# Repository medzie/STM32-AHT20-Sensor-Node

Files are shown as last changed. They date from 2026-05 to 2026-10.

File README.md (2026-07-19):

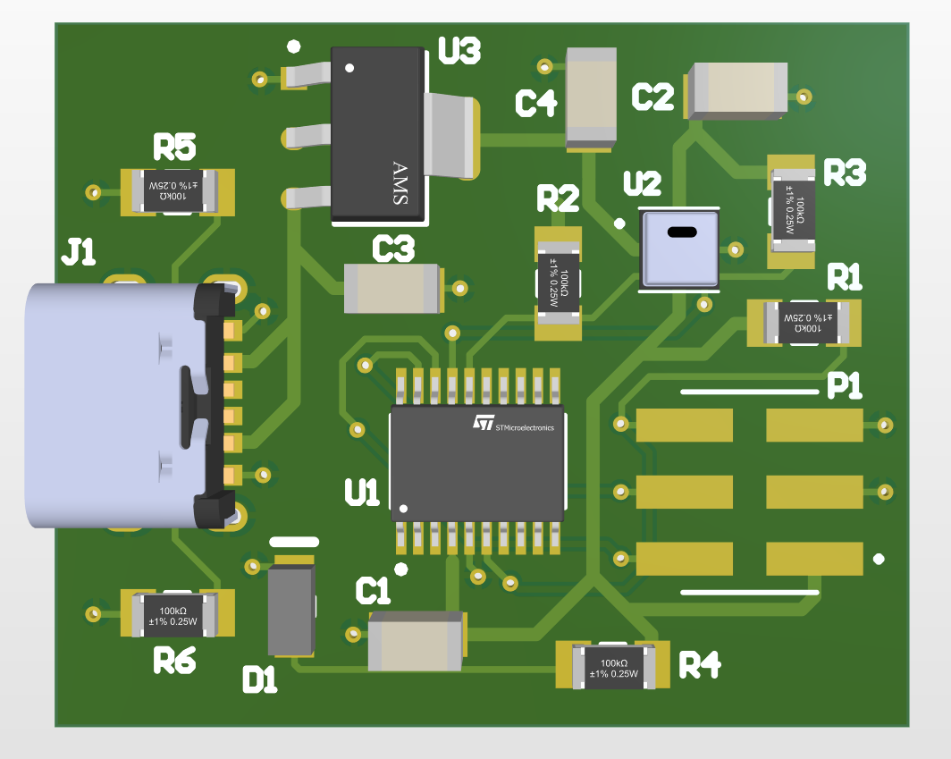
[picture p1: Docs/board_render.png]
STM32 AHT20 Sensor Node Board Render


# STM32 Environmental Sensor (AHT20)

## Overview
This project is a custom environmental sensor node designed to measure temperature and humidity. It is built around the STM32G030F6P6 microcontroller and the AHT20 sensor. The goal of the project was to design a complete hardware-software system, from the schematic and PCB layout to bare-metal firmware implementation.

## Key Features
* **Microcontroller:** STM32G030F6P6 (Cortex-M0+).
* **Sensor:** AHT20 (I2C interface) for high-accuracy climate monitoring.
* **Power Supply:** USB-C 6-pin interface with 5V to 3.3V regulation.
* **Programming:** Standard 2x3 SWD header for ST-Link.
* **Firmware:** Developed in C using direct register access (Bare-Metal).

## Hardware Design
The hardware was designed in Altium Designer. 

**[View Full Schematic (PDF)](Docs/schema.pdf)**

Key design choices include:
* **Voltage Regulation:** AMS1117-3.3 (SOT-223) to provide stable power for the MCU and sensor.
* **USB-C Integration:** 5.1kΩ pull-down resistors on CC1/CC2 lines to ensure compatibility with modern USB-C chargers.
* **Component Selection:** Primarily SMD 1206 footprints for easy manual assembly while maintaining a compact form factor.
* **PCB:** 2-layer design with a solid ground plane for improved EMI performance.

## Project Structure
* `/hardware` - Altium Designer schematics and PCB layout files.
* `/software` - Source code (C), including I2C drivers and peripheral initialization.
* `/Docs` - Datasheets, technical documentation, and project media.

## Learning Objectives
* Mastering professional PCB design workflow in Altium Designer.
* Understanding I2C communication protocol at the register level.
* Implementing hardware-specific features like USB-C power negotiation.

Project developed as part of technical self-education in Embedded Systems.

---

## Project Presentation

### Live Sensor Readings (STM32CubeIDE)
AHT20 Readings

### Assembled Hardware Board
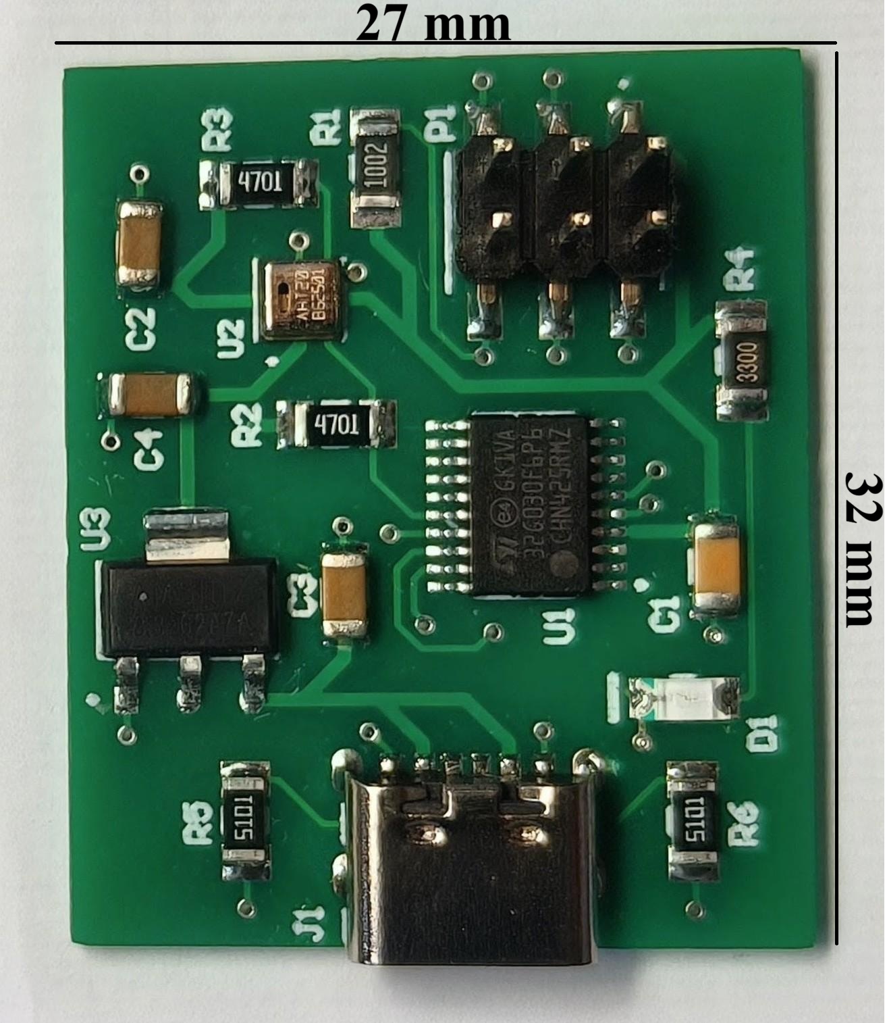
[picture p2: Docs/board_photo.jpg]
Assembled Board


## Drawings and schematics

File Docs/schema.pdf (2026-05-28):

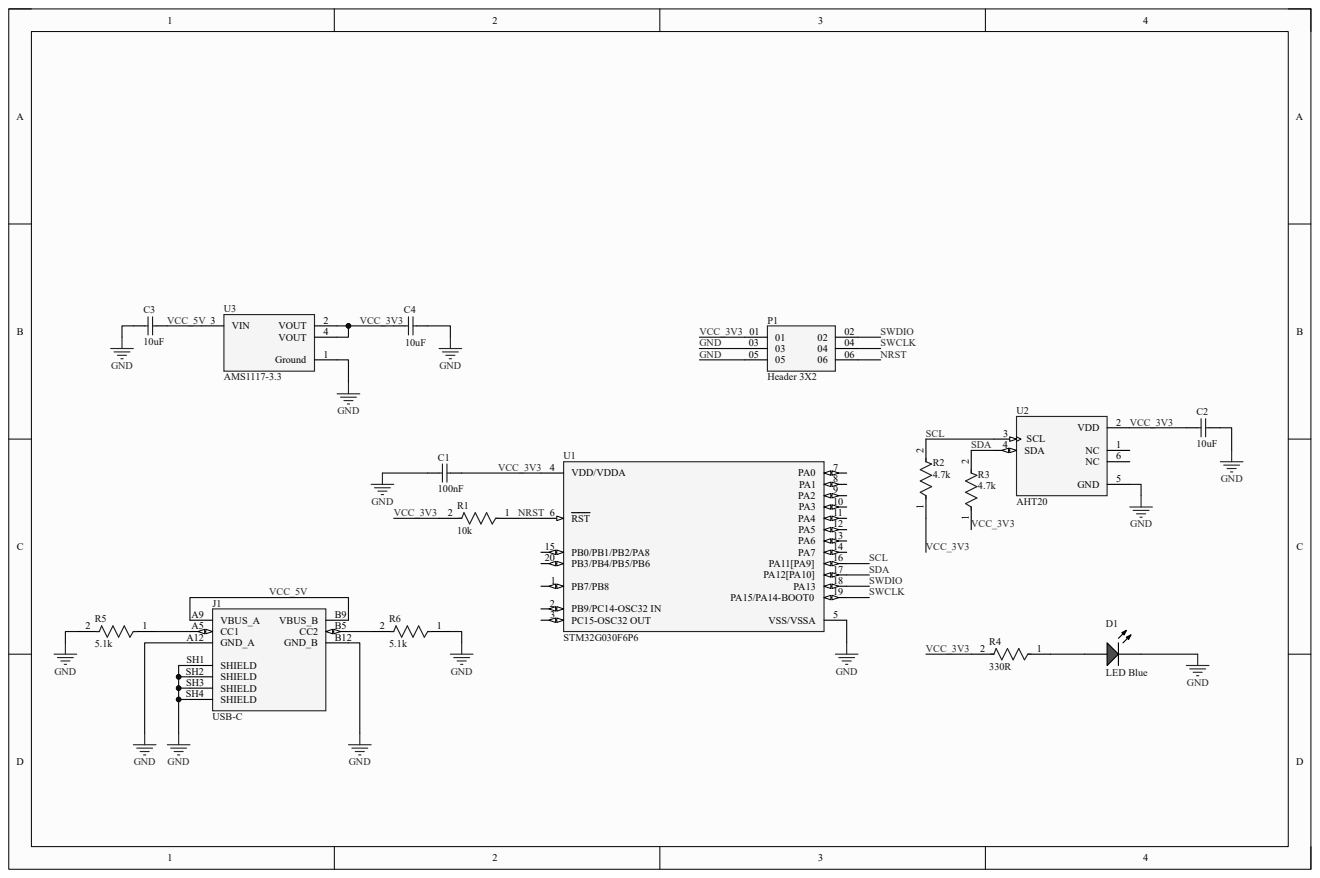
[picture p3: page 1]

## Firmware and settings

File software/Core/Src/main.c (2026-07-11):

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
/* Includes ------------------------------------------------------------------*/
#include "main.h"

I2C_HandleTypeDef hi2c1;

/* USER CODE BEGIN PV */
#define AHT20_ADDR (0x38 << 1)

float temperature = 0.0f;
float humidity = 0.0f;
uint8_t aht20_buf[6];
HAL_StatusTypeDef sensorStatus = 0;
/* USER CODE END PV */

void SystemClock_Config(void);
static void MX_GPIO_Init(void);
static void MX_I2C1_Init(void);
/**
  * @brief  The application entry point.
  * @retval int
  */
int main(void)
{

  /* MCU Configuration--------------------------------------------------------*/

  /* Reset of all peripherals, Initializes the Flash interface and the Systick. */
  HAL_Init();

  /* Configure the system clock */
  SystemClock_Config();

  /* Initialize all configured peripherals */
  MX_GPIO_Init();
  MX_I2C1_Init();
  /* USER CODE BEGIN 2 */
  HAL_Delay(100);
  sensorStatus = HAL_I2C_IsDeviceReady(&hi2c1, AHT20_ADDR, 3, 100);
  uint8_t init_cmd[] = {0xBE, 0x08, 0x00};
  HAL_I2C_Master_Transmit(&hi2c1, AHT20_ADDR, init_cmd, 3, HAL_MAX_DELAY);
  HAL_Delay(10);
  /* USER CODE END 2 */

  /* Infinite loop */
  /* USER CODE BEGIN WHILE */
  while (1)
  {
    /* USER CODE END WHILE */

    /* USER CODE BEGIN 3 */
	    uint8_t meas_cmd[] = {0xAC, 0x33, 0x00};
	    HAL_I2C_Master_Transmit(&hi2c1, AHT20_ADDR, meas_cmd, 3, HAL_MAX_DELAY);

	    HAL_Delay(80);

	    if (HAL_I2C_Master_Receive(&hi2c1, AHT20_ADDR, aht20_buf, 6, HAL_MAX_DELAY) == HAL_OK) {
	  	  if ((aht20_buf[0] & 0x80) == 0) {
	  		  uint32_t raw_humidity = (((uint32_t)aht20_buf[1] << 12) | ((uint32_t)aht20_buf[2] << 4) | ((uint32_t)aht20_buf[3] >> 4));
	  		humidity = ((float)raw_humidity / 1048576.0f) * 100.0f;

	  		  uint32_t raw_temperature = (((uint32_t)(aht20_buf[3] & 0x0F) << 16) | ((uint32_t)aht20_buf[4] << 8) | (uint32_t)aht20_buf[5]);
	  		  temperature = ((float)raw_temperature / 1048576.0f) * 200.0f - 50.0f;
	  	  }
	    }

	    HAL_Delay(2000);
  }
  /* USER CODE END 3 */
}

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


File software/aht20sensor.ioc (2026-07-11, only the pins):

Mcu.UserName=STM32G030F6Px
PA13.Signal=SYS_SWDIO
PA14-BOOT0.Signal=SYS_SWCLK

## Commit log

2026-05-13 Initial commit: base schematic and blank PCB
    [mySensor.PrjPcb, mySensor.SchDoc, mySensor_PCB.PcbDoc]
2026-05-15 Complete routing and ground plane implementation
    Finished most of the PCB layout, including optimized 45-degree trace geometry and power delivery. Implemented GND copper pour on the bottom layer and correctly routed decoupling capacitors for the STM32.
    [mySensor.PrjPcb, mySensor.SchDoc, mySensor_PCB.PcbDoc]
2026-05-16 fix drc violations and optimize ground planes
    [mySensor.PrjPcb, mySensor.SchDoc, mySensor_PCB.PcbDoc]
2026-05-16 fix D1 footprint to LED 1206, remove connector mounting holes
    [mySensor.PrjPcb, mySensor.SchDoc, mySensor_PCB.PcbDoc]
2026-05-25 Fix P1 + R and C footprints constraints
    [mySensor.SchDoc, mySensor_PCB.PcbDoc]
2026-05-25 Optimize track geometry and align pad entries
    [mySensor_PCB.PcbDoc]
2026-05-25 Move PrjPcb to hardware folder
    [mySensor.PrjPcb]
2026-05-25 Move SchDoc to hardware folder
    [mySensor.SchDoc]
2026-05-25 Move PcbDoc to hardware folder
    [mySensor_PCB.PcbDoc]
2026-05-25 Add datasheet stm32g030c6
2026-05-25 Add datasheet AMS1117 3.3V
2026-05-25 Add board render image
2026-05-25 Add PCB render
2026-05-28 Enhance README with schematic link and design details
2026-07-11 Add clean STM32 project into software folder
2026-07-19 Add board photo
2026-10-08 Add dimensions to board photo

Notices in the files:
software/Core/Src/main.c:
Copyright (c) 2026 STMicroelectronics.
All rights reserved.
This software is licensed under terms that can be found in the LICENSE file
